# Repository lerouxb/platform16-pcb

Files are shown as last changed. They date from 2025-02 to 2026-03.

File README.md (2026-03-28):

# platform 16 PCB

This is the KiCad project for **platform 16** — a compact digital synthesizer built around the Raspberry Pi RP2350 microcontroller. The board hosts 16 potentiometers for real-time parameter control, a high-quality audio output chain, and USB-C for power and an SWD port for development.

## Overview

Platform 16 is a self-contained generative synthesizer platform. The hardware is designed to pair with swappable firmware engines — each one turns the same 16 knobs into a different instrument. A companion [front panel editor](https://github.com/lerouxb/platform16-editor) (web app) generates printable overlays so you can label the knobs for whichever [firmware](https://github.com/lerouxb/plaform16-firmware) is loaded.

## Key Components

| Component | Part | Role |
|---|---|---|
| MCU | **RP2350** (QFN-60) | Dual-core Cortex-M33 — runs synthesis DSP, reads pots, drives I2S audio |
| DAC | **PCM5100A** (TI) | 32-bit stereo I2S DAC — converts digital audio to line-level analog |
| Headphone amp | **PAM8908JER** | Capless stereo headphone amplifier — drives headphones without coupling caps |
| Flash | **W25Q128JVS** (Winbond) | 16 MB QSPI flash for firmware and data storage |
| Analog mux | **CD74HC4067SM** | 16-channel analog multiplexer — reads all 16 pots through a single ADC channel |
| Voltage regulator | **NCP1117-3.3** | 3.3 V LDO powered from USB 5 V |
| Audio jacks | **PJ-320D-A** (×3) | 3.5 mm TRS jacks edge-mounted through board notches |
| Connector | **USB-C 16-pin** | Power and data (with proper CC resistors for USB-C detection) |

## Board Details

- **Dimensions:** ~112 mm × 86 mm with rounded corners
- **Mounting:** 4 × M3 mounting holes in a 69 mm × 46 mm rectangle
- **Audio jacks:** Semicircular edge cutouts allow the 3.5 mm jack barrels to protrude through the top edge
- **Passives:** 0402 throughout for a compact layout
- **Potentiometers:** 16 × 10 kΩ through-hole pots (the namesake of the project)
- **Buttons:** 2 × tactile switches for boot mode and reset

## Architecture

```
USB-C (5V)
  │
  ├─► NCP1117 → 3.3V rail
  │
  ▼
RP2350 ──I2S──► PCM5100A (DAC) ──► PAM8908 (amp) ──► 3.5mm jacks
  │
  ├─► CD74HC4067 mux ◄── 16 pots
  ├─► QSPI flash (W25Q128)
  ├─► 2 buttons
  └─► Clock in/out
```

## Schematic

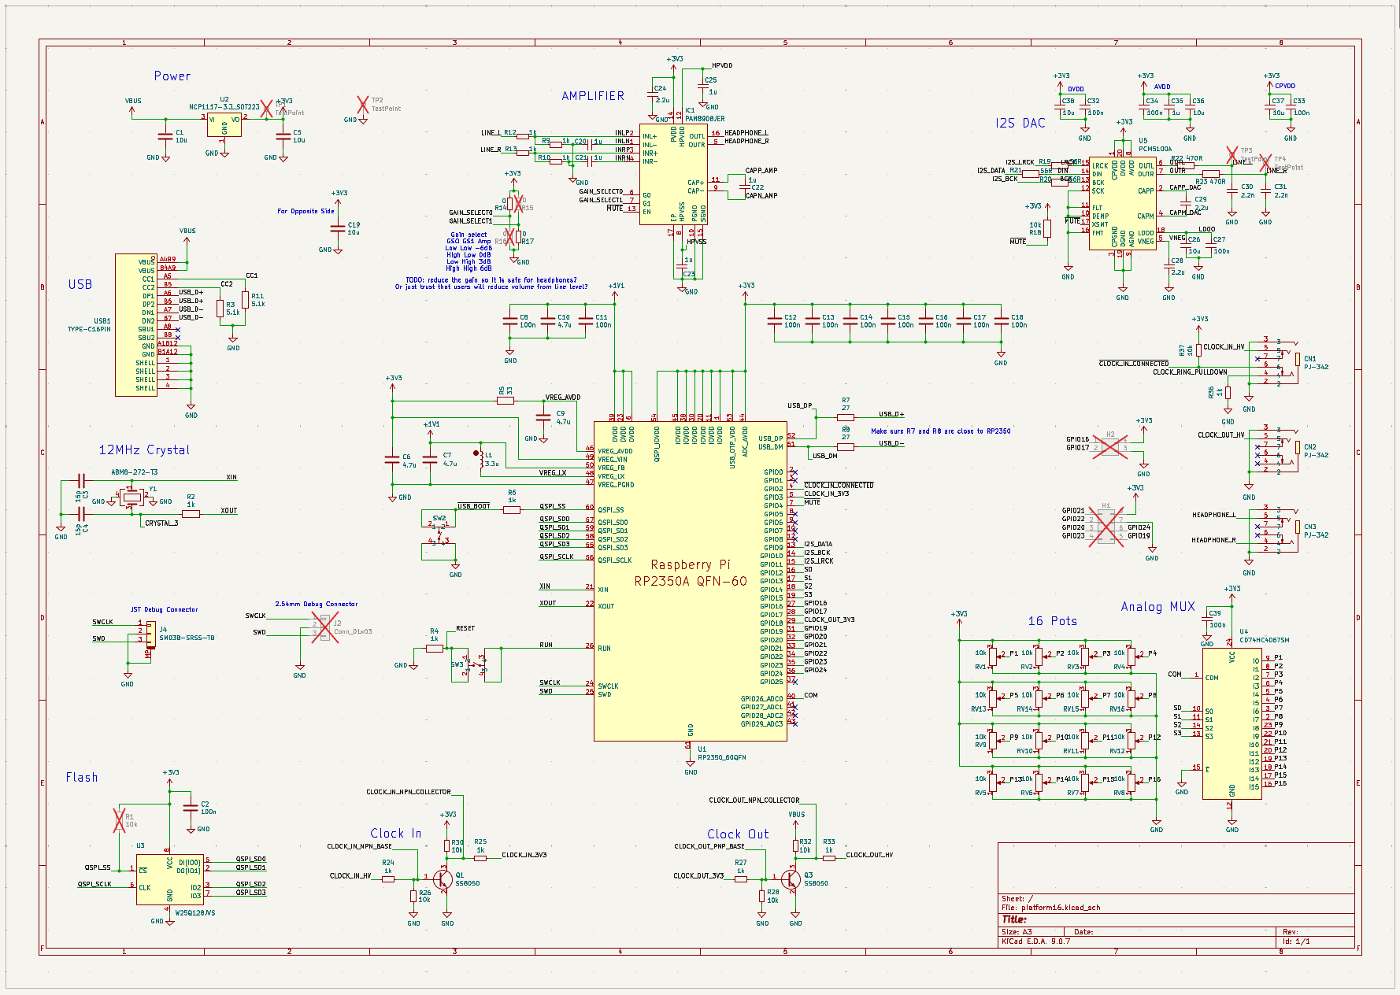
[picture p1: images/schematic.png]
schematic


## PCB Layout

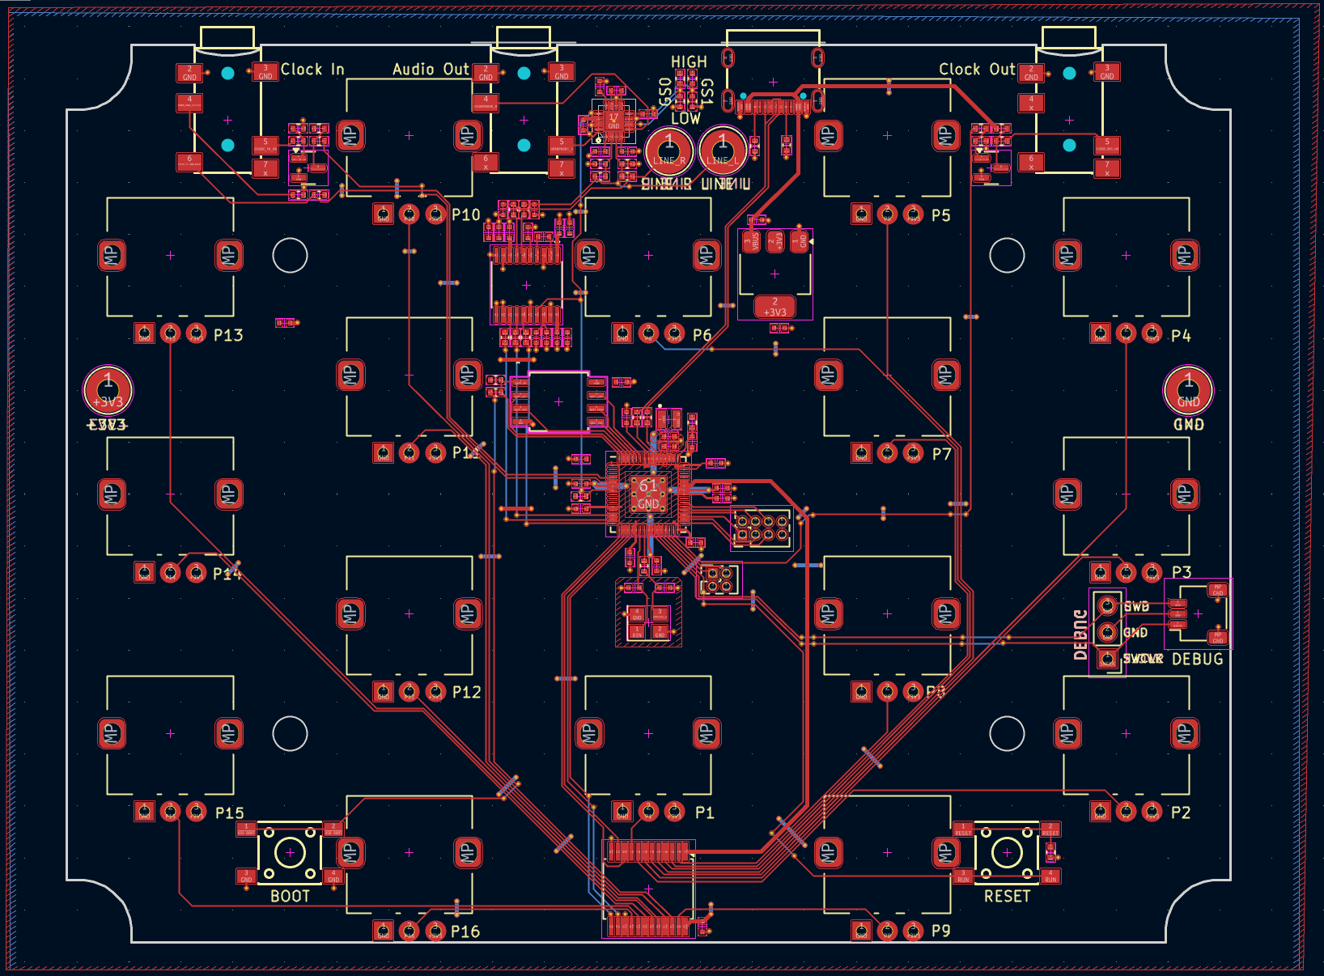
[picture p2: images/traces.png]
traces


## 3D Render

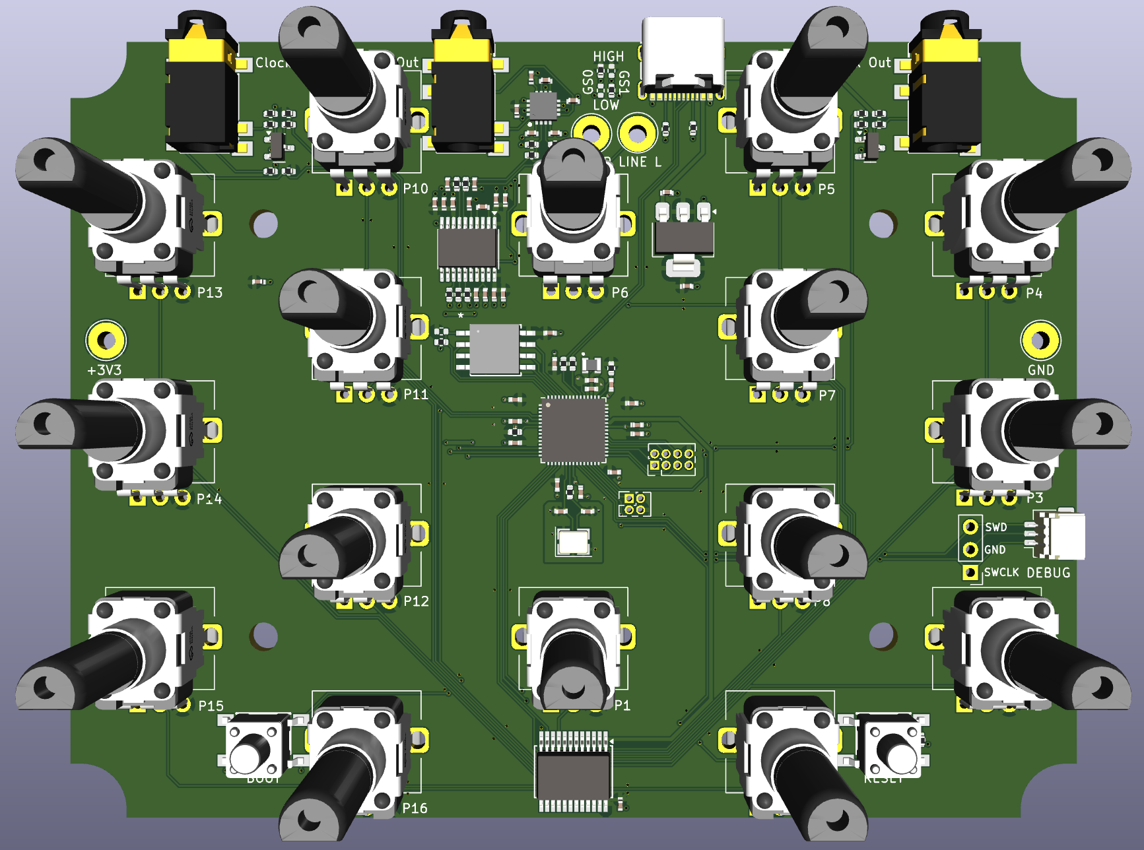
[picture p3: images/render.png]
render


## Related Projects

- **[Firmware](https://github.com/lerouxb/plaform16-firmware)** — C++ (Pico SDK) running on the RP2350. Three swappable generative synth engines:
  - **SDS** — Stochastic Decay Subtractive (PolyBLEP saw + Moog ladder filter, random sequencer)
  - **PMD** — Phase Modulation with Decay (2-operator FM triads, dual LFOs)
  - **TEP** — Two-tone Euclidean Polymeters (dual detunable saws, 3 independent Euclidean rhythms)
- **[Front Panel Editor](https://github.com/lerouxb/platform16-editor)** — React/TypeScript web app for designing printable panel overlays with labelled knobs matching each firmware's control layout

## Tools

- **KiCad 9.0** — schematic and PCB design
- **Fabrication Toolkit** — JLC-compatible production output (BOM, positions, netlist in `production/`)

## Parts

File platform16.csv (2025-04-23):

Reference | Value | Footprint | Qty | DNP | LCSC
C1,C5,C19,C36,C37,C38 | 10u | Capacitor_SMD:C_0402_1005Metric | 6 |  | C15525
C2,C8,C11,C12,C13,C14,C15,C16,C17,C18,C27,C32,C33,C34,C39 | 100n | Capacitor_SMD:C_0402_1005Metric | 15 |  | C1525
C3,C4 | 15p | Capacitor_SMD:C_0402_1005Metric | 2 |  | C1548
C6,C7,C9,C10 | 4.7u | Capacitor_SMD:C_0402_1005Metric | 4 |  | C23733
C20,C21,C22,C23,C25,C26,C35 | 1u | Capacitor_SMD:C_0402_1005Metric | 7 |  | C52923
C24,C28,C29 | 2.2u | Capacitor_SMD:C_0402_1005Metric | 3 |  | C12530
C30,C31 | 2.2n | Capacitor_SMD:C_0402_1005Metric | 2 |  | C915853
D1,D2 | 1N4148WS | Diode_SMD:D_SOD-323 | 2 |  | C2128
IC1 | PAM8908JER | PAM8908JER:QFN50P300X300X65-17N | 1 |  | C33233
J2,J5,J6 | PJ-320D-A | PJ-320D-A:HRO_PJ-320D-A | 3 |  | C431535
J4 | SM03B-SRSS-TB | Connector_JST:JST_SH_SM03B-SRSS-TB_1x03-1MP_P1.00mm_Horizontal | 1 |  | C160403
L1 | 3.3u | RP2350_60QFN_minimal:L_pol_2016 | 1 |  | C42411119
Q1,Q3 | SS8050 | Package_TO_SOT_SMD:SOT-23 | 2 |  | C2150
Q2,Q4 | SS8550 | Package_TO_SOT_SMD:SOT-23 | 2 |  | C8542
R1,R18 | 10k | Resistor_SMD:R_0402_1005Metric | 2 | -- mixed values -- | C25744
R2,R4,R6,R9,R10,R12,R13,R29,R35 | 1k | Resistor_SMD:R_0402_1005Metric | 9 |  | C11702
R3,R11 | 5.1k | Resistor_SMD:R_0402_1005Metric | 2 |  | C25905
R5 | 33 | Resistor_SMD:R_0402_1005Metric | 1 |  | C25105
R7,R8 | 27 | Resistor_SMD:R_0402_1005Metric | 2 |  | C138021
R14,R15,R16,R17 | 0 | Resistor_SMD:R_0402_1005Metric | 4 | -- mixed values -- | C17168
R19,R20,R21 | 56R | Resistor_SMD:R_0402_1005Metric | 3 |  | C137957
R22,R23 | 470R | Resistor_SMD:R_0402_1005Metric | 2 |  | C25117
R24,R25,R26,R27,R28,R30,R31,R32,R33,R34 | 47k | Resistor_SMD:R_0402_1005Metric | 10 |  | C25792
RV1,RV2,RV3,RV4,RV5,RV6,RV7,RV8,RV9,RV10,RV11,RV12,RV13,RV14,RV15,RV16 | 10k | potentiometer:potentiometer | 16 |  | C470448
SW1,SW2 | Switch | Button_Switch_SMD:SW_SPST_PTS810 | 2 |  | C455282
U1 | RP2350_60QFN | RP2350_60QFN_minimal:RP2350-QFN-60-1EP_7x7_P0.4mm_EP3.4x3.4mm_ThermalVias | 1 |  | C42411118
U2 | NCP1117-3.3_SOT223 | Package_TO_SOT_SMD:SOT-223-3_TabPin2 | 1 |  | C26537
U3 | W25Q128JVS | SOIC_208MIL_WIN:SOIC_208MIL_WIN | 1 |  | C97521
U4 | CD74HC4067SM | Package_SO:SSOP-24_5.3x8.2mm_P0.65mm | 1 |  | C98457
U5 | PCM5100A | Package_SO:TSSOP-20_4.4x6.5mm_P0.65mm | 1 |  | C131154
USB1 | TYPE-C16PIN | easyeda2kicad:USB-C-SMD_TYPE-C16PIN | 1 |  | C393939
Y1 | ABM8-272-T3 | Crystal:Crystal_SMD_3225-4Pin_3.2x2.5mm | 1 |  | C20625731

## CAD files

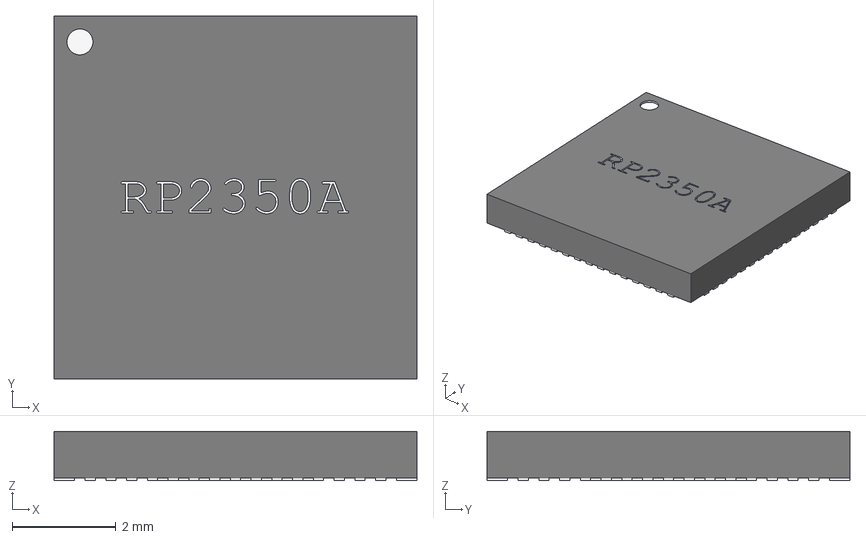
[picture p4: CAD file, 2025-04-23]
RP2350_QFN60.step
7.00 x 7.00 x 0.95 mm

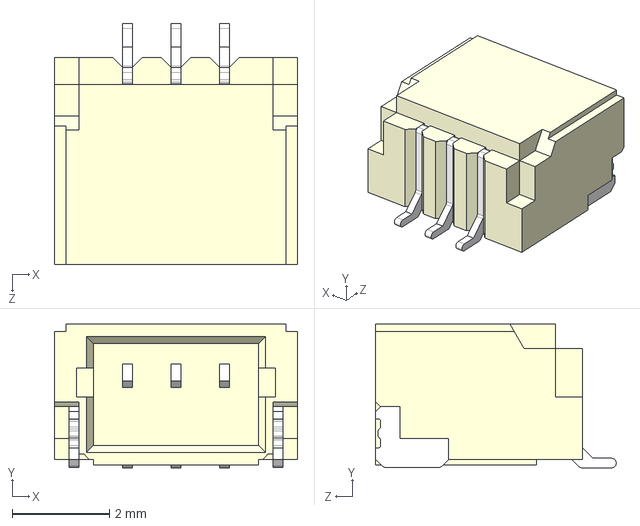
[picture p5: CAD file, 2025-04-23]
SM03B-SRSS-TB(LF)(SN)--3DModel-STEP-56544.STEP
5.00 x 2.96 x 4.95 mm

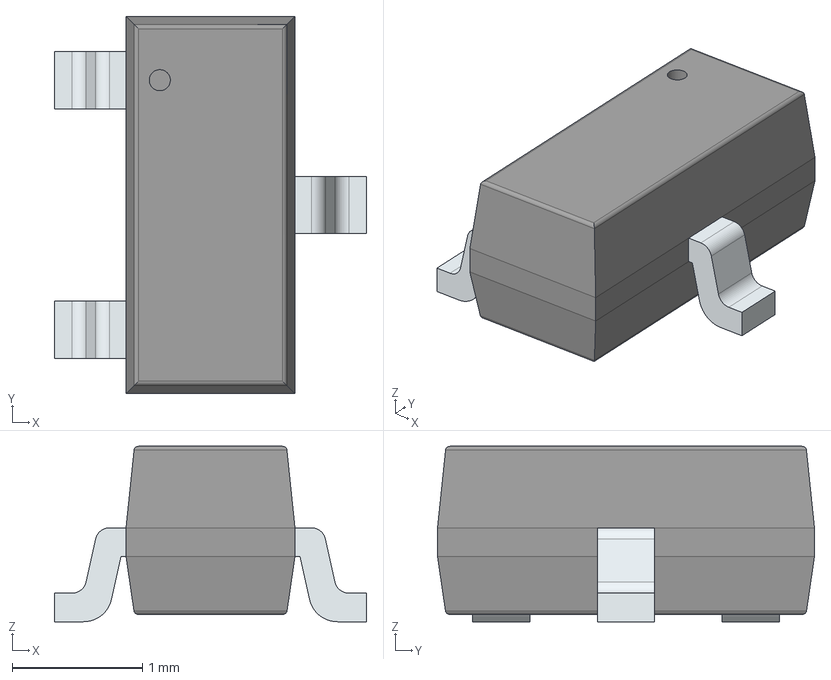
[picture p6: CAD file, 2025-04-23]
AP7333-33SRG-7.stp
2.40 x 2.90 x 1.35 mm
PinsArrayL
FilletPinR

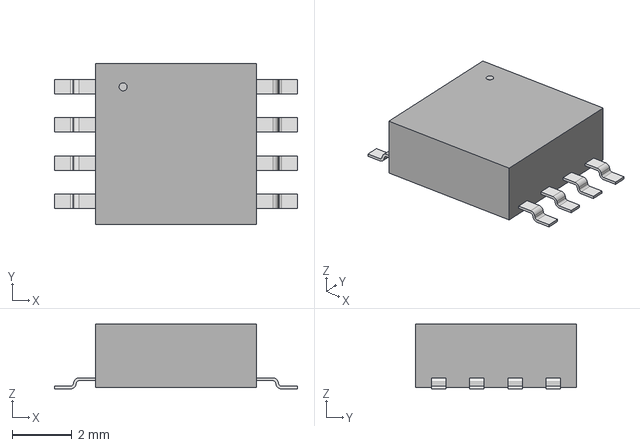
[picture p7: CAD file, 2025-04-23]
SOIC_208MIL_WIN.step
8.10 x 5.38 x 2.16 mm

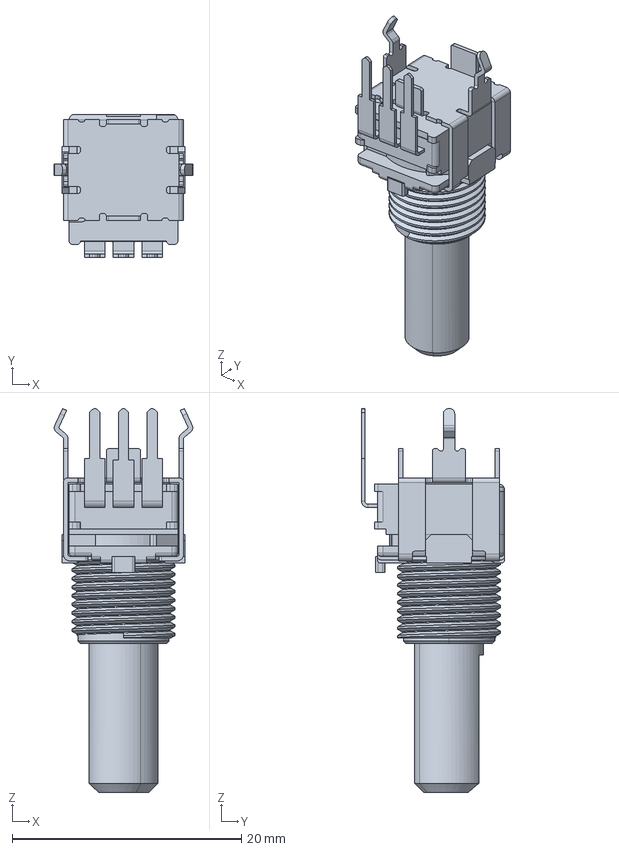
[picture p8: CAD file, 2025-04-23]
rk09l1140a2u.stp
12.1 x 12.5 x 33.5 mm

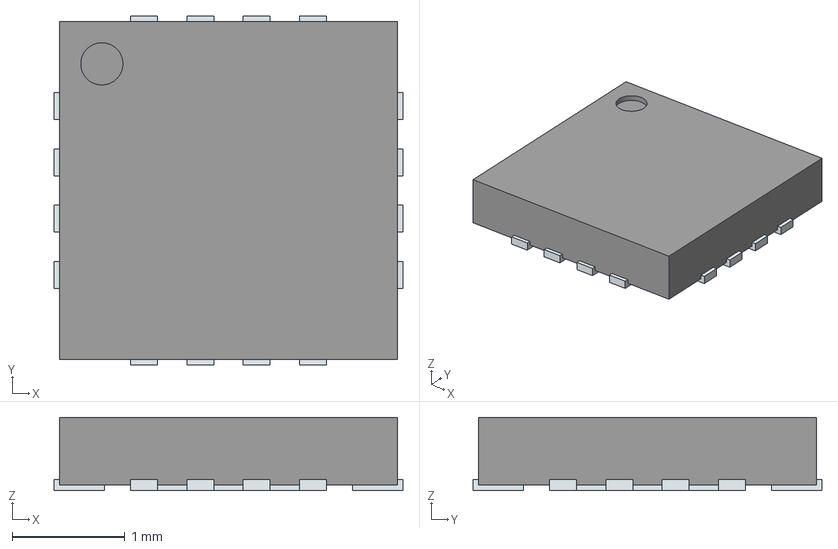
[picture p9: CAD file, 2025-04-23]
PAM8908JER.stp
3.10 x 3.10 x 0.65 mm
ThermalPin
PinsArrayLR
PinsArrayTB

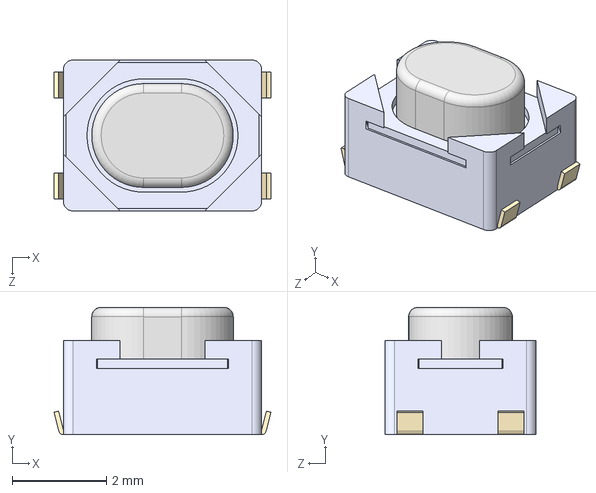
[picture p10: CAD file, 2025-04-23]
PTS810SJM250SMTR LFS.STEP
4.60 x 2.70 x 3.20 mm

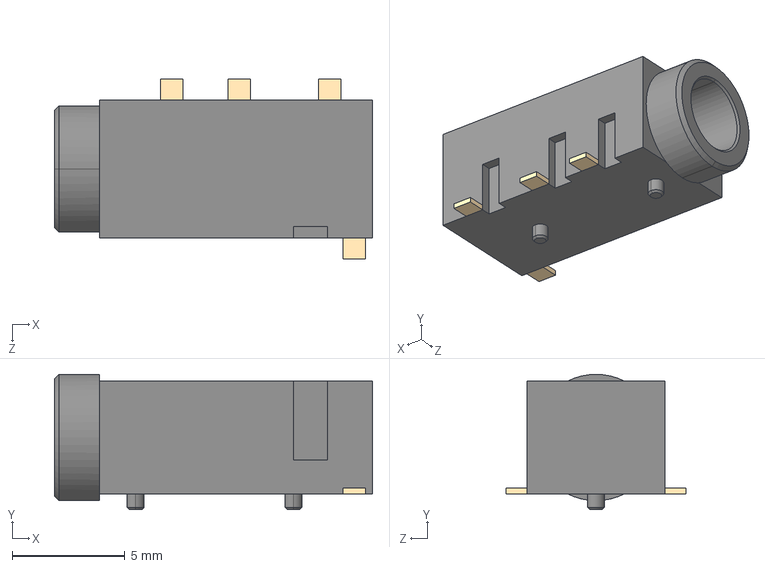
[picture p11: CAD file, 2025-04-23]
PJ-320D-A.step
14.1 x 6.00 x 8.00 mm

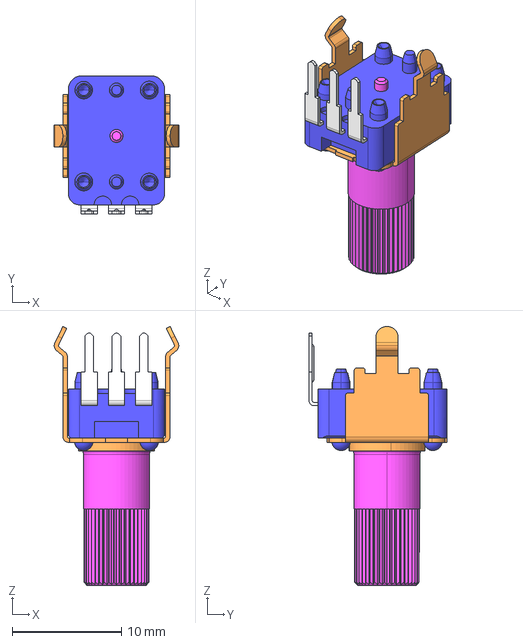
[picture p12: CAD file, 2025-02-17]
rk09k1130a5r.stp
11.4 x 12.7 x 23.7 mm

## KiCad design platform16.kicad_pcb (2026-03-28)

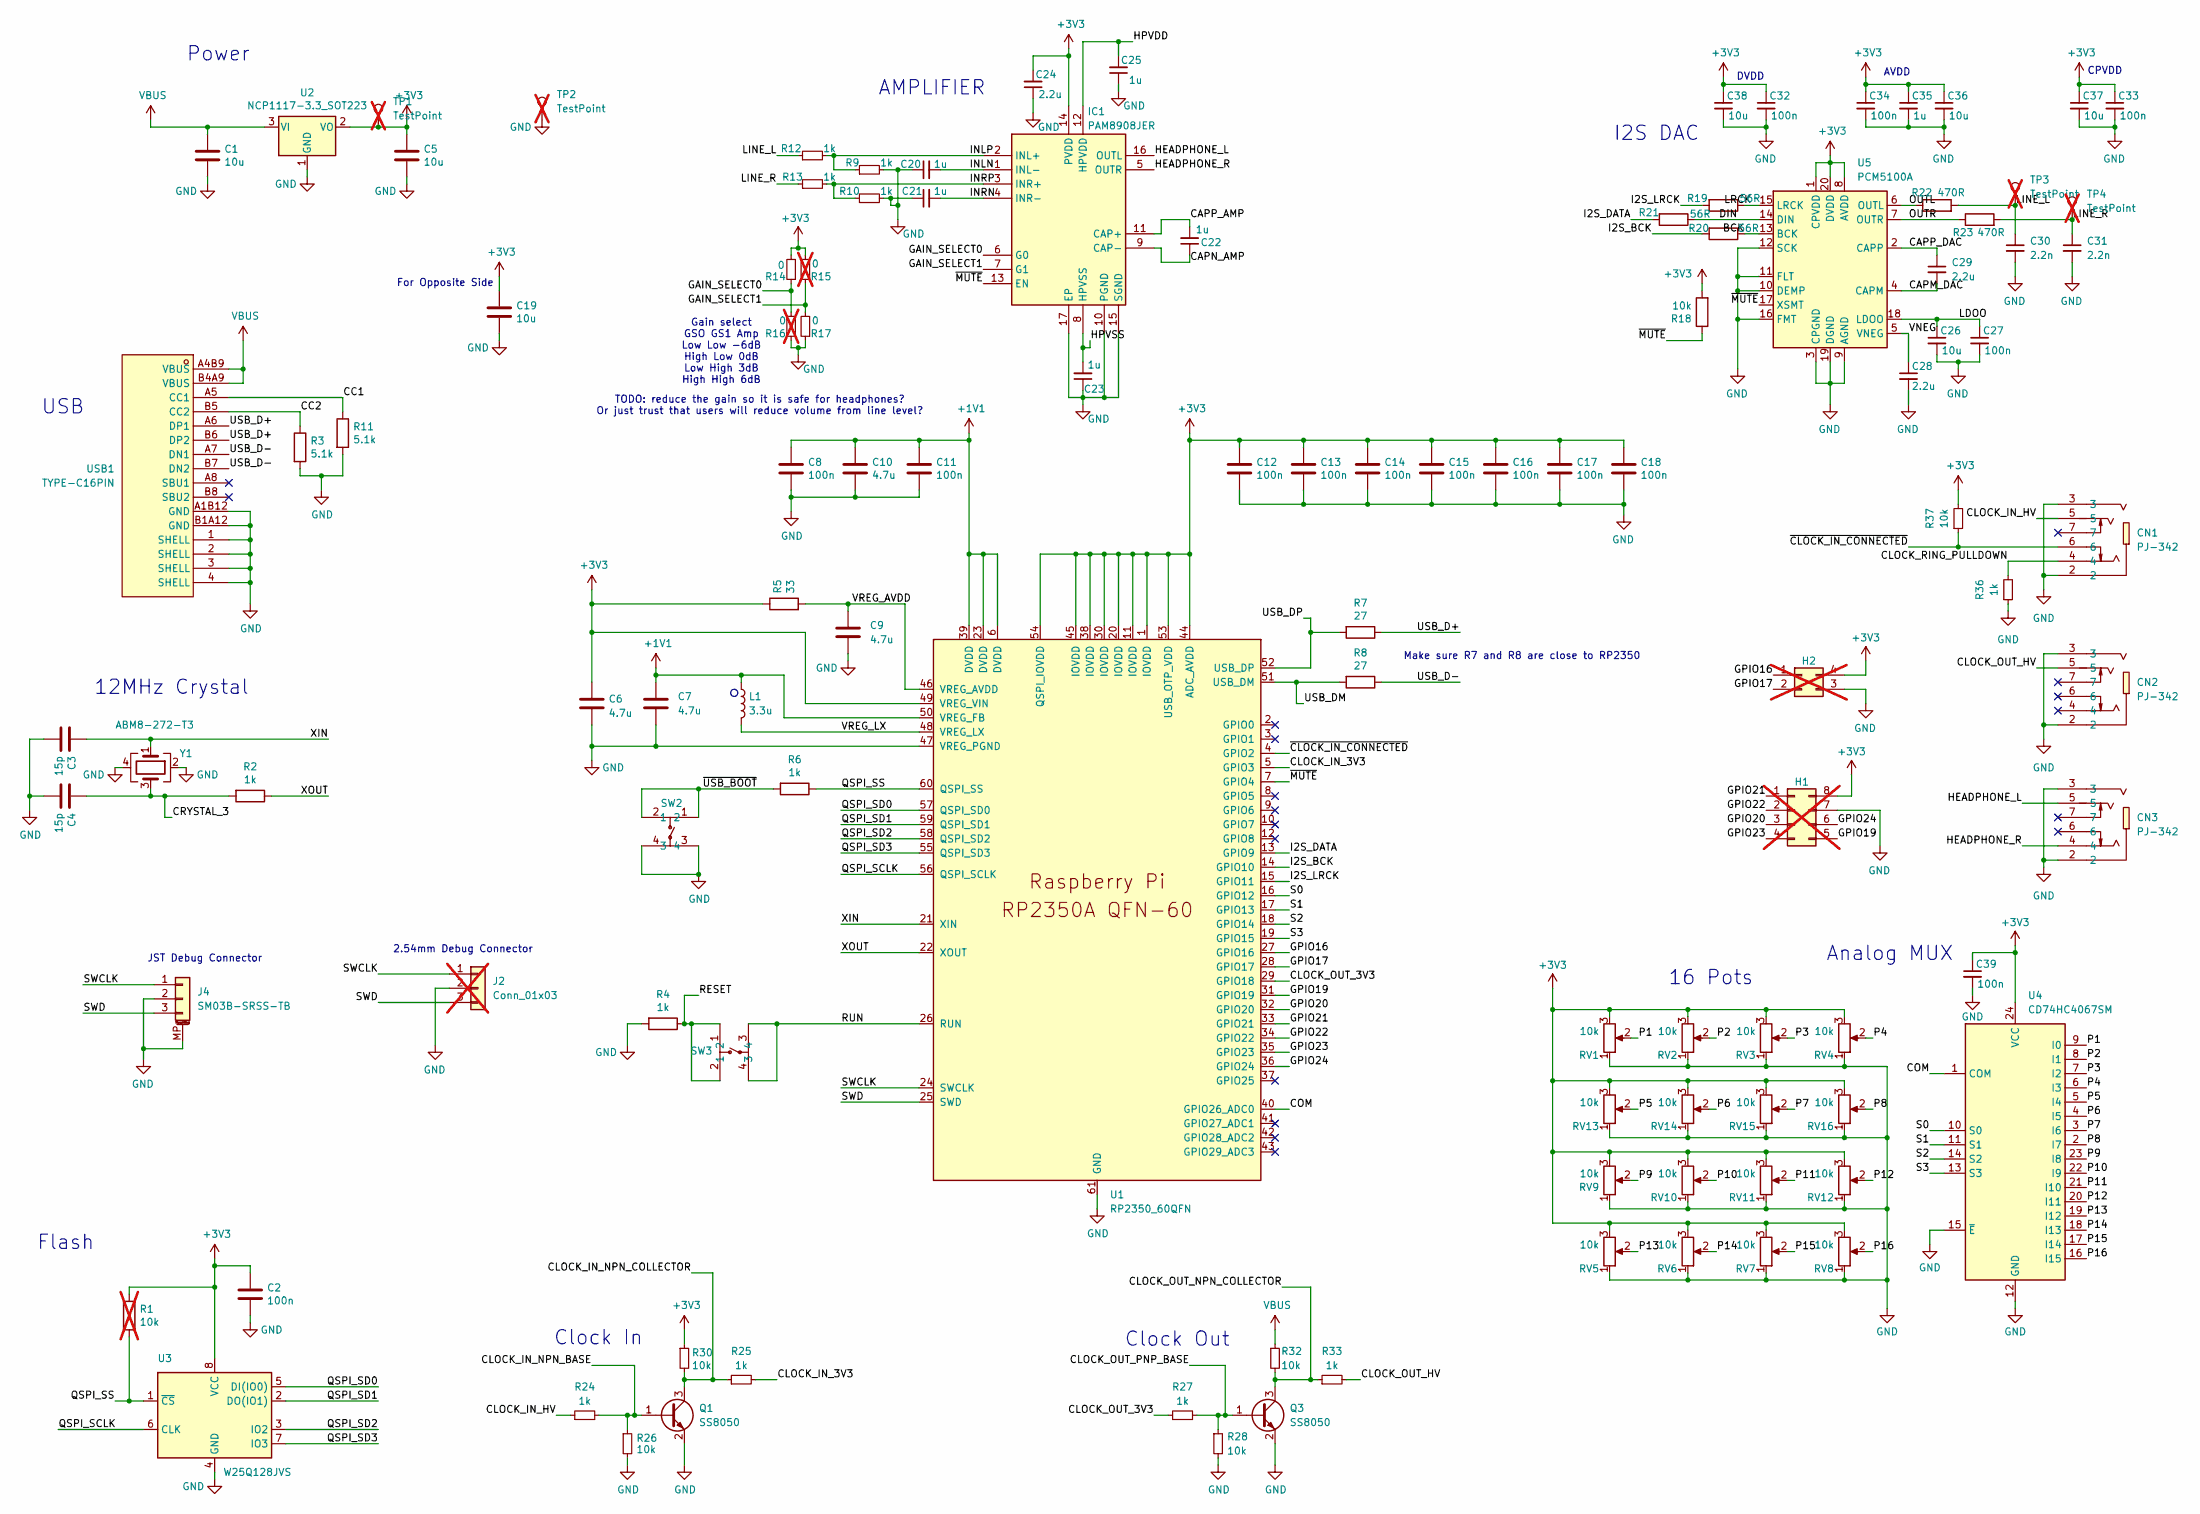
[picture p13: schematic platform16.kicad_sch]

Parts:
C1, C5, C19, C26, C36, C37, C38: 10u; C_0402_1005Metric_small_pads; LCSC C15525
C2, C8, C11, C12, C13, C14, C15, C16, C17, C18, C27, C32, C33, C34, C39: 100n; C_0402_1005Metric_small_pads; LCSC C1525
C3, C4: 15p; C_0402_1005Metric_small_pads; LCSC C1548
C6, C7, C9, C10: 4.7u; C_0402_1005Metric_small_pads; LCSC C23733
C20, C21, C22, C23, C25, C35: 1u; C_0402_1005Metric_small_pads; LCSC C52923
C24, C28, C29: 2.2u; C_0402_1005Metric_small_pads; LCSC C12530
C30, C31: 2.2n; C_0402_1005Metric_small_pads; LCSC C915853
CN1, CN2, CN3: PJ-342; AUDIO-SMD_PJ-342; LCSC C668606
H1: Conn_02x04_Counter_Clockwise; PinHeader_2x04_P1.27mm_Vertical; not fitted
H2: Conn_02x02_Counter_Clockwise; PinHeader_2x02_P1.27mm_Vertical; not fitted
IC1: PAM8908JER; QFN50P300X300X65-17N; Manufacturer_Part_Number PAM8908JER; Mouser Part Number 621-PAM8908JER
J2: Conn_01x03; PinHeader_1x03_P2.54mm_Vertical; not fitted
J4: SM03B-SRSS-TB; JST_SH_SM03B-SRSS-TB_1x03-1MP_P1.00mm_Horizontal; LCSC C160403
L1: 3.3u; L_pol_2016; LCSC C42411119
Q1, Q3: SS8050; SOT-23; LCSC C2150
R1: 10k; R_0402_1005Metric; LCSC C25744; not fitted
R2, R4, R6, R9, R10, R12, R13, R24, R25, R27, R33, R36: 1k; R_0402_1005Metric; LCSC C11702
R3, R11: 5.1k; R_0402_1005Metric; LCSC C25905
R5: 33; R_0402_1005Metric; LCSC C25105
R7, R8: 27; R_0402_1005Metric; LCSC C138021
R14, R17: 0; R_0402_1005Metric; LCSC C17168
R15, R16: 0; R_0402_1005Metric; LCSC C17168; not fitted
R18, R26, R28, R30, R32, R37: 10k; R_0402_1005Metric; LCSC C25744
R19, R20, R21: 56R; R_0402_1005Metric; LCSC C137957
R22, R23: 470R; R_0402_1005Metric; LCSC C25117
RV1, RV2, RV3, RV4, RV5, RV6, RV7, RV8, RV9, RV10, RV11, RV12, RV13, RV14, RV15, RV16: 10k; potentiometer; LCSC C470305
SW2, SW3: TS-1095PS-A165B2-C3D2; SW-SMD_4P-L6.0-W6.0-P4.50-LS9.2; LCSC C782843
TP1, TP2, TP3, TP4: TestPoint; TestPoint_THTPad_D4.0mm_Drill2.0mm; not fitted
U1: RP2350_60QFN; RP2350-QFN-60-1EP_7x7_P0.4mm_EP3.4x3.4mm_ThermalVias; LCSC C42411118
U2: NCP1117-3.3_SOT223; SOT-223-3_TabPin2; LCSC C26537
U3: W25Q128JVS; SOIC_208MIL_WIN; LCSC C97521
U4: CD74HC4067SM; SSOP-24_5.3x8.2mm_P0.65mm; LCSC C98457
U5: PCM5100A; TSSOP-20_4.4x6.5mm_P0.65mm; LCSC C131154
USB1: TYPE-C16PIN; USB-C-SMD_TYPE-C16PIN; LCSC Part C393939
Y1: ABM8-272-T3; Crystal_SMD_3225-4Pin_3.2x2.5mm; LCSC C20625731

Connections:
+1V1: C7.1, C8.1, C10.1, C11.1, L1.1, U1.6 (DVDD), U1.23 (DVDD), U1.39 (DVDD), U1.50 (VREG_FB)
+3V3: C2.1, C5.1, C6.1, C12.1, C13.1, C14.1, C15.1, C16.1, C17.1, C18.1, C19.1, C24.2, C32.1, C33.1, C34.1, C35.1, C36.1, C37.1, C38.1, C39.1, H1.8, H2.4, IC1.14 (PVDD), R1.1, R5.1, R14.2, R15.2, R18.2, R30.1, R37.2, RV1.3, RV2.3, RV3.3, RV4.3, RV5.3, RV6.3, RV7.3, RV8.3, RV9.3, RV10.3, RV11.3, RV12.3, RV13.3, RV14.3, RV15.3, RV16.3, TP1.1, U1.1 (IOVDD), U1.11 (IOVDD), U1.20 (IOVDD), U1.30 (IOVDD), U1.38 (IOVDD), U1.44 (ADC_AVDD), U1.45 (IOVDD), U1.49 (VREG_VIN), U1.53 (USB_OTP_VDD), U1.54 (QSPI_IOVDD), U2.2 (VO), U3.8 (VCC), U4.24 (VCC), U5.1 (CPVDD), U5.8 (AVDD), U5.20 (DVDD)
/BCK: R20.1, U5.13 (BCK)
/CAPM_DAC: C29.2, U5.4 (CAPM)
/CAPN_AMP: C22.1, IC1.9 (CAP-)
/CAPP_AMP: C22.2, IC1.11 (CAP+)
/CAPP_DAC: C29.1, U5.2 (CAPP)
/CC1: R11.1, USB1.A5 (CC1)
/CC2: R3.1, USB1.B5 (CC2)
/CLOCK_IN_3V3: R25.2, U1.5 (GPIO3)
/CLOCK_IN_HV: CN1.5, R24.1
/CLOCK_IN_NPN_BASE: Q1.1 (B), R24.2, R26.1
/CLOCK_IN_NPN_COLLECTOR: Q1.3 (C), R25.1, R30.2
/CLOCK_OUT_3V3: R27.1, U1.29 (GPIO18)
/CLOCK_OUT_HV: CN2.5, R33.2
/CLOCK_OUT_NPN_COLLECTOR: Q3.3 (C), R32.2, R33.1
/CLOCK_OUT_PNP_BASE: Q3.1 (B), R27.2, R28.1
/CLOCK_RING_PULLDOWN: CN1.4, R36.2
/COM: U1.40 (GPIO26_ADC0), U4.1 (COM)
/CRYSTAL_3: C4.1, R2.2, Y1.3
/DIN: R21.1, U5.14 (DIN)
/GAIN_SELECT0: IC1.6 (G0), R14.1, R16.2
/GAIN_SELECT1: IC1.7 (G1), R15.1, R17.2
/GPIO16: H2.1, U1.27 (GPIO16)
/GPIO17: H2.2, U1.28 (GPIO17)
/GPIO19: H1.5, U1.31 (GPIO19)
/GPIO20: H1.3, U1.32 (GPIO20)
/GPIO21: H1.1, U1.33 (GPIO21)
/GPIO22: H1.2, U1.34 (GPIO22)
/GPIO23: H1.4, U1.35 (GPIO23)
/GPIO24: H1.6, U1.36 (GPIO24)
/HEADPHONE_L: CN3.5, IC1.16 (OUTL)
/HEADPHONE_R: CN3.4, IC1.5 (OUTR)
/HPVDD: C25.2, IC1.12 (HPVDD)
/HPVSS: C23.2, IC1.8 (HPVSS)
/I2S_BCK: R20.2, U1.14 (GPIO10)
/I2S_DATA: R21.2, U1.13 (GPIO9)
/I2S_LRCK: R19.2, U1.15 (GPIO11)
/INLN: C20.2, IC1.1 (INL-)
/INLP: IC1.2 (INL+), R9.1, R12.2
/INRN: C21.2, IC1.4 (INR-)
/INRP: IC1.3 (INR+), R10.1, R13.2
/LDOO: C26.1, C27.1, U5.18 (LDOO)
/LINE_L: C30.1, R12.1, R22.2, TP3.1
/LINE_R: C31.1, R13.1, R23.2, TP4.1
/LRCK: R19.1, U5.15 (LRCK)
/OUTL: R22.1, U5.6 (OUTL)
/OUTR: R23.1, U5.7 (OUTR)
/P1: RV1.2, U4.9 (I0)
/P2: RV2.2, U4.8 (I1)
/P3: RV3.2, U4.7 (I2)
/P4: RV4.2, U4.6 (I3)
/P5: RV13.2, U4.5 (I4)
/P6: RV14.2, U4.4 (I5)
/P7: RV15.2, U4.3 (I6)
/P8: RV16.2, U4.2 (I7)
/P9: RV9.2, U4.23 (I8)
/P10: RV10.2, U4.22 (I9)
/P11: RV11.2, U4.21 (I10)
/P12: RV12.2, U4.20 (I11)
/P13: RV5.2, U4.19 (I12)
/P14: RV6.2, U4.18 (I13)
/P15: RV7.2, U4.17 (I14)
/P16: RV8.2, U4.16 (I15)
/QSPI_SCLK: U1.56 (QSPI_SCLK), U3.6 (CLK)
/QSPI_SD0: U1.57 (QSPI_SD0), U3.5 (DI(IO0))
/QSPI_SD1: U1.59 (QSPI_SD1), U3.2 (DO(IO1))
/QSPI_SD2: U1.58 (QSPI_SD2), U3.3 (IO2)
/QSPI_SD3: U1.55 (QSPI_SD3), U3.7 (IO3)
/QSPI_SS: R1.2, R6.1, U1.60 (QSPI_SS), U3.1 (~CS)
/RESET: R4.1, SW3.1, SW3.2
/RUN: SW3.3, SW3.4, U1.26 (RUN)
/S0: U1.16 (GPIO12), U4.10 (S0)
/S1: U1.17 (GPIO13), U4.11 (S1)
/S2: U1.18 (GPIO14), U4.14 (S2)
/S3: U1.19 (GPIO15), U4.13 (S3)
/SWCLK: J2.1, J4.1, U1.24 (SWCLK)
/SWD: J2.3, J4.3, U1.25 (SWD)
/USB_D+: R7.1, USB1.A6 (DP1), USB1.B6 (DP2)
/USB_D-: R8.1, USB1.A7 (DN1), USB1.B7 (DN2)
/USB_DM: R8.2, U1.51 (USB_DM)
/USB_DP: R7.2, U1.52 (USB_DP)
/VNEG: C28.1, U5.5 (VNEG)
/VREG_AVDD: C9.1, R5.2, U1.46 (VREG_AVDD)
/VREG_LX: L1.2, U1.48 (VREG_LX)
/XIN: C3.1, U1.21 (XIN), Y1.1
/XOUT: R2.1, U1.22 (XOUT)
/~CLOCK_IN_CONNECTED: CN1.6, R37.1, U1.4 (GPIO2)
/~MUTE: IC1.13 (EN), R18.1, U1.7 (GPIO4), U5.17 (XSMT)
/~USB_BOOT: R6.2, SW2.1, SW2.2
GND: C1.2, C2.2, C3.2, C4.2, C5.2, C6.2, C7.2, C8.2, C9.2, C10.2, C11.2, C12.2, C13.2, C14.2, C15.2, C16.2, C17.2, C18.2, C19.2, C20.1, C21.1, C23.1, C24.1, C25.1, C26.2, C27.2, C28.2, C30.2, C31.2, C32.2, C33.2, C34.2, C35.2, C36.2, C37.2, C38.2, C39.2, CN1.2, CN1.3, CN2.2, CN2.3, CN3.2, CN3.3, H1.7, H2.3, IC1.10 (PGND), IC1.15 (SGND), IC1.17 (EP), J2.2, J4.2, J4.MP (MountPin), Q1.2 (E), Q3.2 (E), R3.2, R4.2, R9.2, R10.2, R11.2, R16.1, R17.1, R26.2, R28.2, R36.1, RV1.1, RV2.1, RV3.1, RV4.1, RV5.1, RV6.1, RV7.1, RV8.1, RV9.1, RV10.1, RV11.1, RV12.1, RV13.1, RV14.1, RV15.1, RV16.1, SW2.3, SW2.4, TP2.1, U1.47 (VREG_PGND), U1.61 (GND), U2.1 (GND), U3.4 (GND), U4.12 (GND), U4.15 (~E), U5.3 (CPGND), U5.9 (AGND), U5.10 (DEMP), U5.11 (FLT), U5.12 (SCK), U5.16 (FMT), U5.19 (DGND), USB1.1 (SHELL), USB1.2 (SHELL), USB1.3 (SHELL), USB1.4 (SHELL), USB1.A1B12 (GND), USB1.B1A12 (GND), Y1.2, Y1.4
VBUS: C1.1, R32.1, U2.3 (VI), USB1.A4B9 (VBUS), USB1.B4A9 (VBUS)

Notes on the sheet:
CPVDD
JST Debug Connector
For Opposite Side
16 Pots
USB
Clock In
AMPLIFIER
AVDD
TODO: reduce the gain so it is safe for headphones? Or just trust that users will reduce volume from line level?
Flash
Clock Out
I2S DAC
2.54mm Debug Connector
Make sure R7 and R8 are close to RP2350
Analog MUX
Gain select GSO GS1 Amp Low Low -6dB High Low 0dB Low High 3dB High High 6dB
DVDD
12MHz Crystal
Power

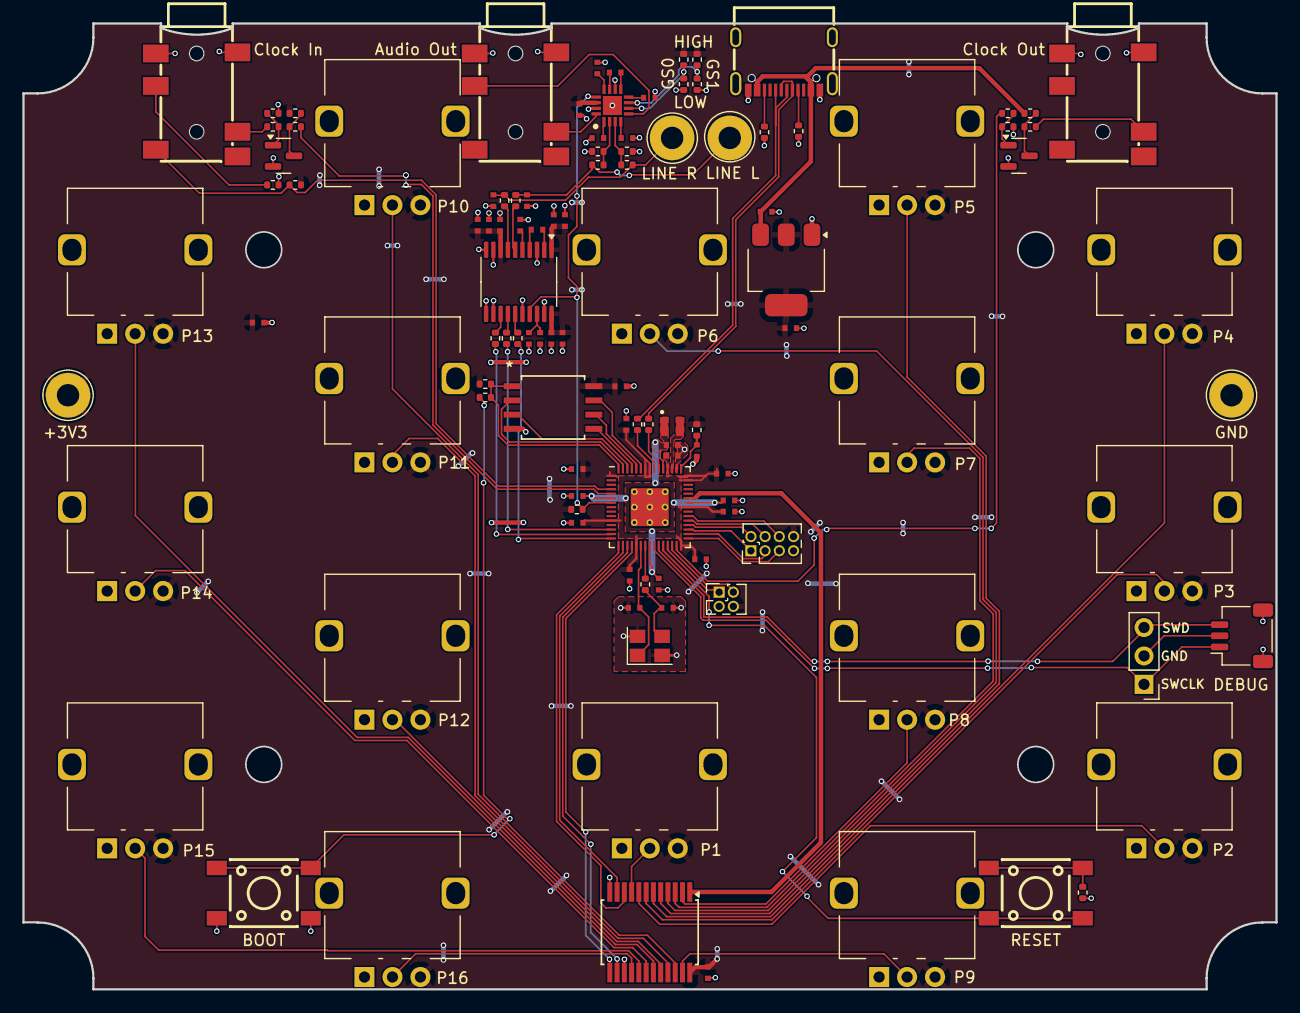
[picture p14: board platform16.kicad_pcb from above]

Board: 2 copper layers, 112.0 x 86.3 mm, 112 parts (0 on the bottom side), 92 nets.

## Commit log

2025-02-17 initial design
    [bom.csv, designators.csv, platform.kicad_pcb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]
2025-04-23 16 pots, clock in, audio out, clock out, boot, reset
    [AP7333-33SRG-7.stp, PAM8908JER.stp, PJ-320D-A.step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]
2025-04-25 move ports around a bit
    [platform16.kicad_pcb]
2025-06-07 another iteration
    [bom.csv, designators.csv, platform16.kicad_pcb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]
2025-06-20 potentiometer tweaks
    [platform16.kicad_pcb, platform16.kicad_sch]
2026-03-28 basic readme
    [bom.csv, platform16.kicad_pcb, platform16.kicad_sch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]
